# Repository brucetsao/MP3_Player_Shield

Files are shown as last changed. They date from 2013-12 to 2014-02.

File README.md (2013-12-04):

MP3 Player Shield 
NOTE: This branch is currently under Revision
==================

[MP3 Player Shield  
*MP3 Player Shield (SEN-11084)*](https://www.sparkfun.com/products/10628)

The MP3 Player Shield has a microSD socket, VS1053 decoder IC and all the supporting circuitry to be able to decode and play MP3s from an Arduino.

Repository Contents
-------------------
* **/firmware** - Multiple examples of how to read MP3 files and send them to the VS1053.
* **/hardware** - All Eagle design files (.brd, .sch)

License Information
-------------------

The hardware is released under [Creative Commons Share-alike 3.0](http://creativecommons.org/licenses/by-sa/3.0/).  

All other code is open source so please feel free to do anything you want with it; you buy me a beer if you use this and we meet someday ([Beerware license](http://en.wikipedia.org/wiki/Beerware)).

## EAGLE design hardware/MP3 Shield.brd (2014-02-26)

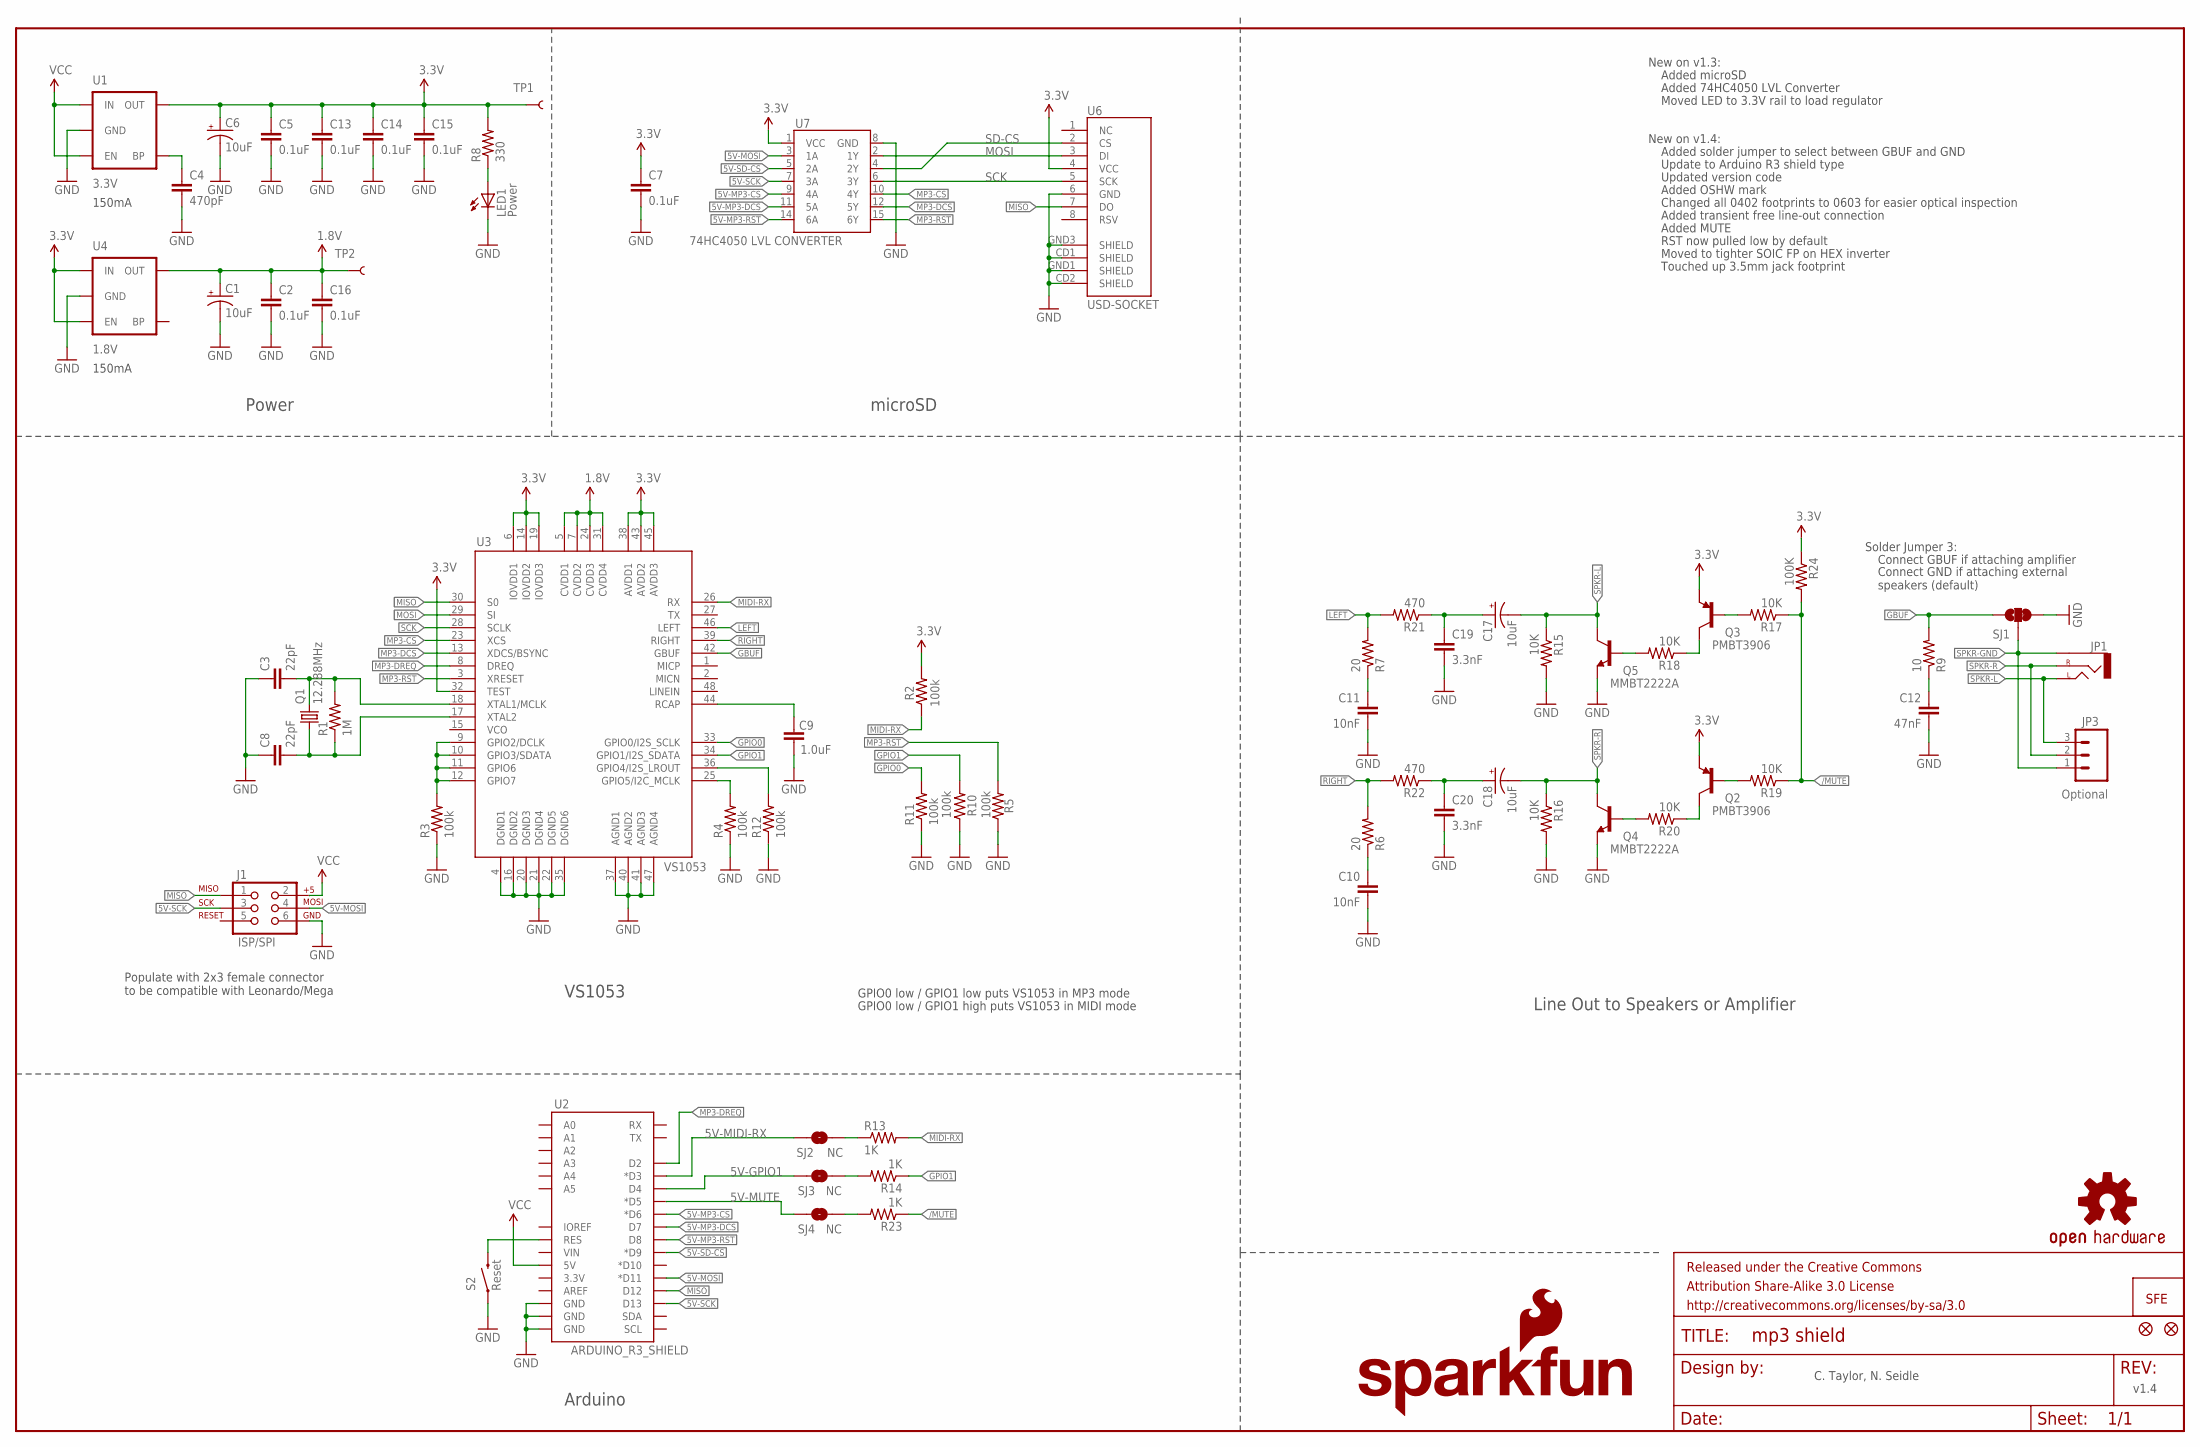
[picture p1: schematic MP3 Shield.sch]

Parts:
C1, C6, C17, C18: 10uF; EIA3216
C2, C5, C7, C13, C14, C15, C16: 0.1uF; 0603-CAP
C3, C8: 22pF; 0603-CAP
C4: 470pF; 0603-CAP
C9: 1.0uF; 0603-CAP
C10, C11: 10nF; 0603-CAP
C12: 47nF; 0603-CAP
C19, C20: 3.3nF; 0603-CAP
FRAME1: FRAME-LEDGER; CREATIVE_COMMONS
J1: ISP/SPI; 2X3
JP1: AUDIO-JACKSMD2; AUDIO-JACK-3.5MM-SMD
JP3: Optional; 1X03
LED1: Power; LED-0603
LOGO1: OSHW-LOGOS; OSHW-LOGO-S
LOGO2: SFE_LOGO_NAME_FLAME.1_INCH; SFE_LOGO_NAME_FLAME_.1
Q1: 12.288MHz; CRYSTAL-SMD-5X3
Q2, Q3: PMBT3906; SOT23-3
Q4, Q5: MMBT2222A; SOT23-3
R1: 1M; 0603-RES
R2, R3, R4, R5, R10, R11, R12: 100k; 0603-RES
R6, R7: 20; 0603-RES
R8: 330; 0603-RES
R9: 10; 0603-RES
R13, R14, R23: 1K; 0603-RES
R15, R16, R17, R18, R19, R20: 10K; 0603-RES
R21, R22: 470; 0603-RES
R24: 100K; 0603-RES
S2: Reset; TACTILE_SWITCH_SMD
SJ1: SOLDERJUMPER_2WAYPASTE2&3; SJ_3_PASTE2&3
SJ2, SJ3, SJ4: NC; SJ_2S-TRACE
TP1, TP2: TEST-POINT3X5; PAD.03X.05
U1: 3.3V; SOT23-5
U2: ARDUINO_R3_SHIELD; UNO_R3_SHIELD
U3: VS1053; LQFP-48
U4: 1.8V; SC70
U6: USD-SOCKET; MICRO-SD-SOCKET-PP
U7: 74HC4050 LVL CONVERTER; SO016
U$4, U$5: FIDUCIAL1X2; FIDUCIAL-1X2
U$8: LOGO-SFENEW; SFE-NEW-WEBLOGO

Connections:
1.8V: C1.A (+), C2.1, C16.1, TP2.P$1, U3.5 (CVDD1), U3.7 (CVDD2), U3.24 (CVDD3), U3.31 (CVDD4), U4.5 (OUT)
3.3V: C5.1, C6.A (+), C7.1, C13.1, C14.1, C15.1, Q2.2 (E), Q3.2 (E), R2.2, R8.2, R24.1, TP1.P$1, U1.5 (OUT), U3.6 (IOVDD1), U3.14 (IOVDD2), U3.19 (IOVDD3), U3.32 (TEST), U3.38 (AVDD1), U3.43 (AVDD2), U3.45 (AVDD3), U4.1 (IN), U4.3 (EN), U6.4 (VCC), U7.1 (VCC)
5V-GPIO1: SJ3.2, U2.D4
5V-MIDI-RX: SJ2.1, U2.D3 (*D3)
5V-MOSI: J1.4, U2.D11 (*D11), U7.3 (1A)
5V-MP3-CS: U2.D6 (*D6), U7.9 (4A)
5V-MP3-DCS: U2.D7, U7.11 (5A)
5V-MP3-RST: U2.D8, U7.14 (6A)
5V-MUTE: SJ4.2, U2.D5 (*D5)
5V-SCK: J1.3, U2.D13, U7.7 (3A)
5V-SD-CS: U2.D9 (*D9), U7.5 (2A)
/MUTE: R17.1, R19.1, R23.1, R24.2
ARST: S2.3 (2), U2.RES
G1: R3.2, U3.9 (GPIO2/DCLK), U3.10 (GPIO3/SDATA), U3.11 (GPIO6), U3.12 (GPIO7)
G2: R4.2, U3.25 (GPIO5/I2C_MCLK)
GBUF: R9.2, SJ1.1, U3.42 (GBUF)
GND: C1.C (-), C2.2, C3.1, C4.2, C5.2, C6.C (-), C7.2, C8.1, C9.1, C10.2, C11.2, C12.2, C13.2, C14.2, C15.2, C16.2, C19.2, C20.2, J1.6, LED1.C, Q4.2 (E), Q5.2 (E), R3.1, R4.1, R5.1, R10.1, R11.1, R12.1, R15.2, R16.2, S2.1, SJ1.3, U1.2 (GND), U2.GND@0 (GND), U2.GND@1 (GND), U2.GND@2 (GND), U3.4 (DGND1), U3.16 (DGND2), U3.20 (DGND3), U3.21 (DGND4), U3.22 (DGND5), U3.35 (DGND6), U3.37 (AGND1), U3.40 (AGND2), U3.41 (AGND3), U3.47 (AGND4), U4.2 (GND), U6.6 (GND), U6.CD1 (SHIELD), U6.CD2 (SHIELD), U6.GND1 (SHIELD), U6.GND3 (SHIELD), U7.8 (GND)
GPIO0: R11.2, U3.33 (GPIO0/I2S_SCLK)
GPIO1: R10.2, R14.1, U3.34 (GPIO1/I2S_SDATA)
GPIO4: R12.2, U3.36 (GPIO4/I2S_LROUT)
LEFT: R7.2, R21.2, U3.46 (LEFT)
MIDI-RX: R2.1, R13.2, U3.26 (RX)
MISO: J1.1, U2.D12, U3.30 (S0), U6.7 (DO)
MOSI: U3.29 (SI), U6.3 (DI), U7.2 (1Y)
MP3-CS: U3.23 (XCS), U7.10 (4Y)
MP3-DCS: U3.13 (XDCS/BSYNC), U7.12 (5Y)
MP3-DREQ: U2.D2, U3.8 (DREQ)
MP3-RST: R5.2, U3.3 (XRESET), U7.15 (6Y)
unnamed: Q4.1 (B), R20.2
unnamed: C12.1, R9.1
unnamed: C10.1, R6.1
unnamed: R14.2, SJ3.1
unnamed: C11.1, R7.1
unnamed: LED1.A, R8.1
unnamed: Q2.3 (C), R20.1
unnamed: R13.1, SJ2.2
unnamed: C3.2, Q1.3 (2), R1.2, U3.18 (XTAL1/MCLK)
unnamed: C8.2, Q1.1, R1.1, U3.17 (XTAL2)
unnamed: Q2.1 (B), R19.2
unnamed: Q5.1 (B), R18.2
unnamed: R23.2, SJ4.1
unnamed: Q3.3 (C), R18.1
unnamed: Q3.1 (B), R17.2
unnamed: C18.A (+), C20.1, R22.1
unnamed: C17.A (+), C19.1, R21.1
unnamed: C4.1, U1.4 (BP)
RCAP: C9.2, U3.44 (RCAP)
RIGHT: R6.2, R22.2, U3.39 (RIGHT)
SCK: U3.28 (SCLK), U6.5 (SCK), U7.6 (3Y)
SD-CS: U6.2 (CS), U7.4 (2Y)
SPKR-GND: JP1.SLEEVE, JP3.1, SJ1.2
SPKR-L: C17.C (-), JP1.TIP (LEFT), JP3.3, Q5.3 (C), R15.1
SPKR-R: C18.C (-), JP1.RING (RIGHT), JP3.2, Q4.3 (C), R16.1
VCC: J1.2, U1.1 (IN), U1.3 (EN), U2.5V

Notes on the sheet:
GPIO0 low / GPIO1 high puts VS1053 in MIDI mode
C. Taylor, N. Seidle
New on v1.3:
GPIO0 low / GPIO1 low puts VS1053 in MP3 mode
microSD
Power
Line Out to Speakers or Amplifier
Arduino
VS1053
Moved LED to 3.3V rail to load regulator
Added microSD
Added 74HC4050 LVL Converter
New on v1.4:
Added solder jumper to select between GBUF and GND
Connect GBUF if attaching amplifier
Connect GND if attaching external speakers (default)
Update to Arduino R3 shield type
Updated version code
Added OSHW mark
Changed all 0402 footprints to 0603 for easier optical inspection
Added transient free line-out connection
Added MUTE
Solder Jumper 3:
150mA
v1.4
RST now pulled low by default
Populate with 2x3 female connector to be compatible with Leonardo/Mega
Moved to tighter SOIC FP on HEX inverter
Touched up 3.5mm jack footprint

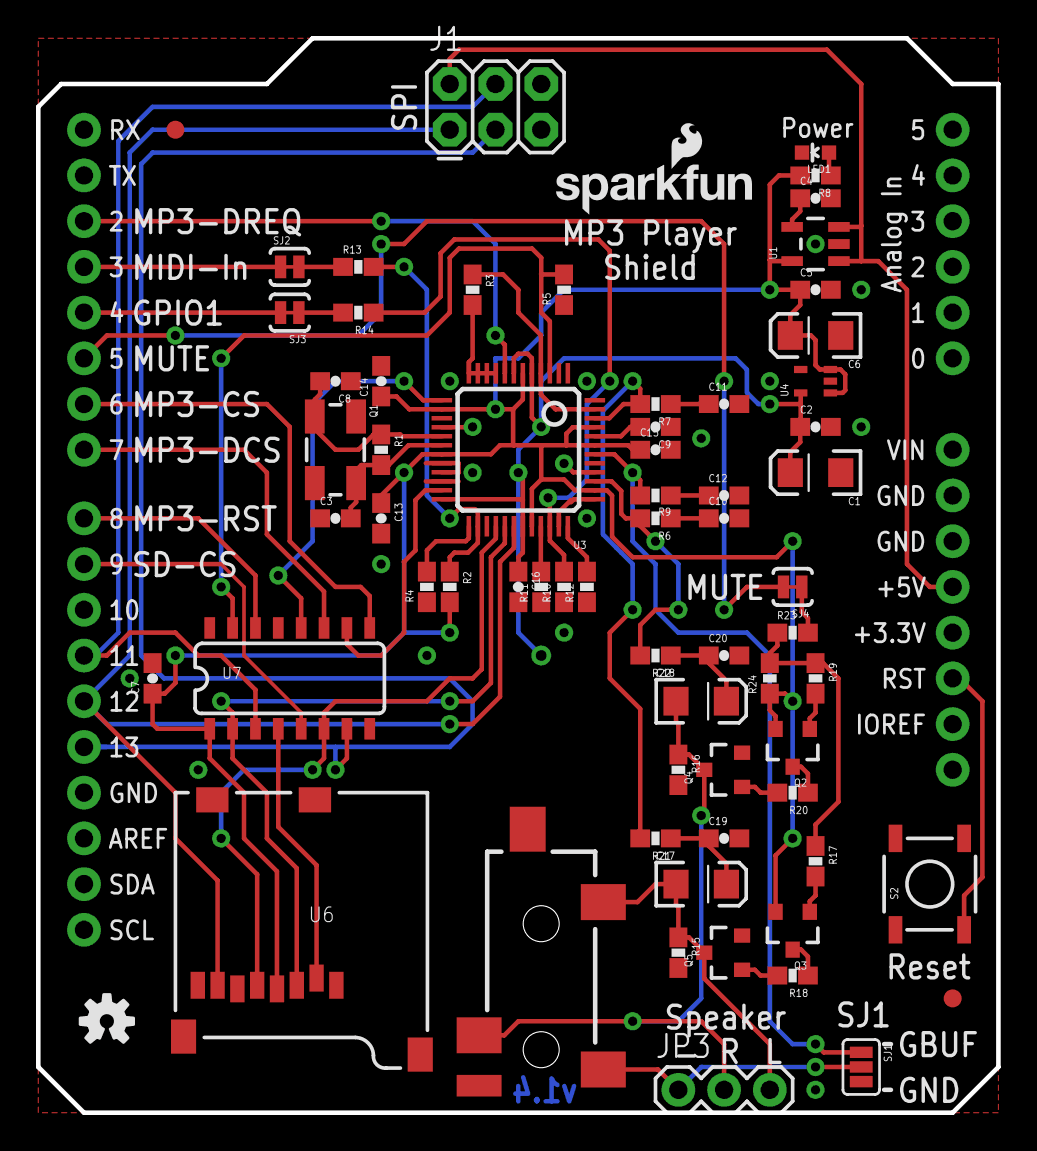
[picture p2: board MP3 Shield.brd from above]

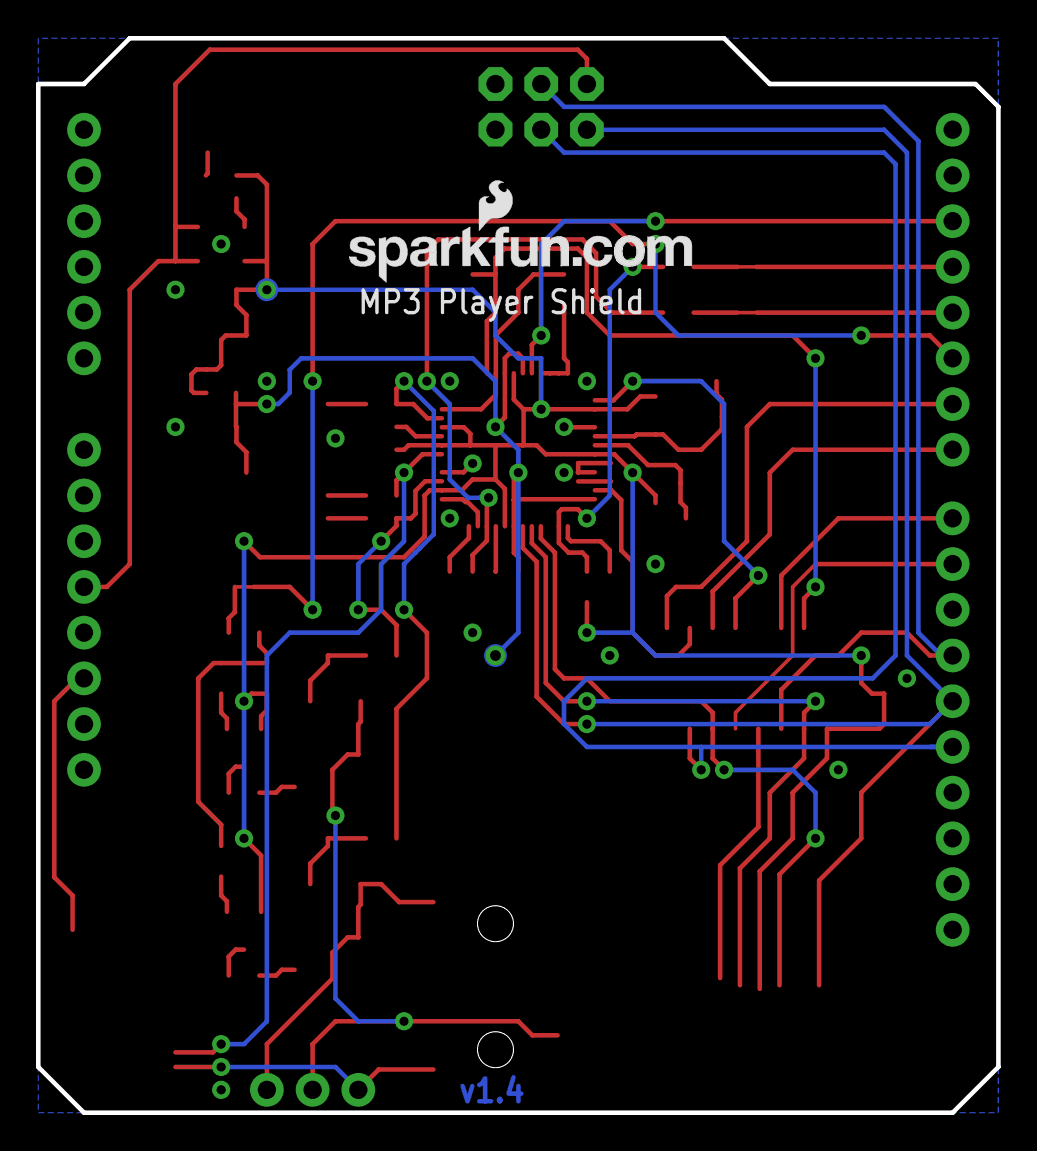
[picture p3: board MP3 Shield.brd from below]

Board: 2 copper layers, 53.3 x 59.7 mm, 72 parts (3 on the bottom side), 54 nets.

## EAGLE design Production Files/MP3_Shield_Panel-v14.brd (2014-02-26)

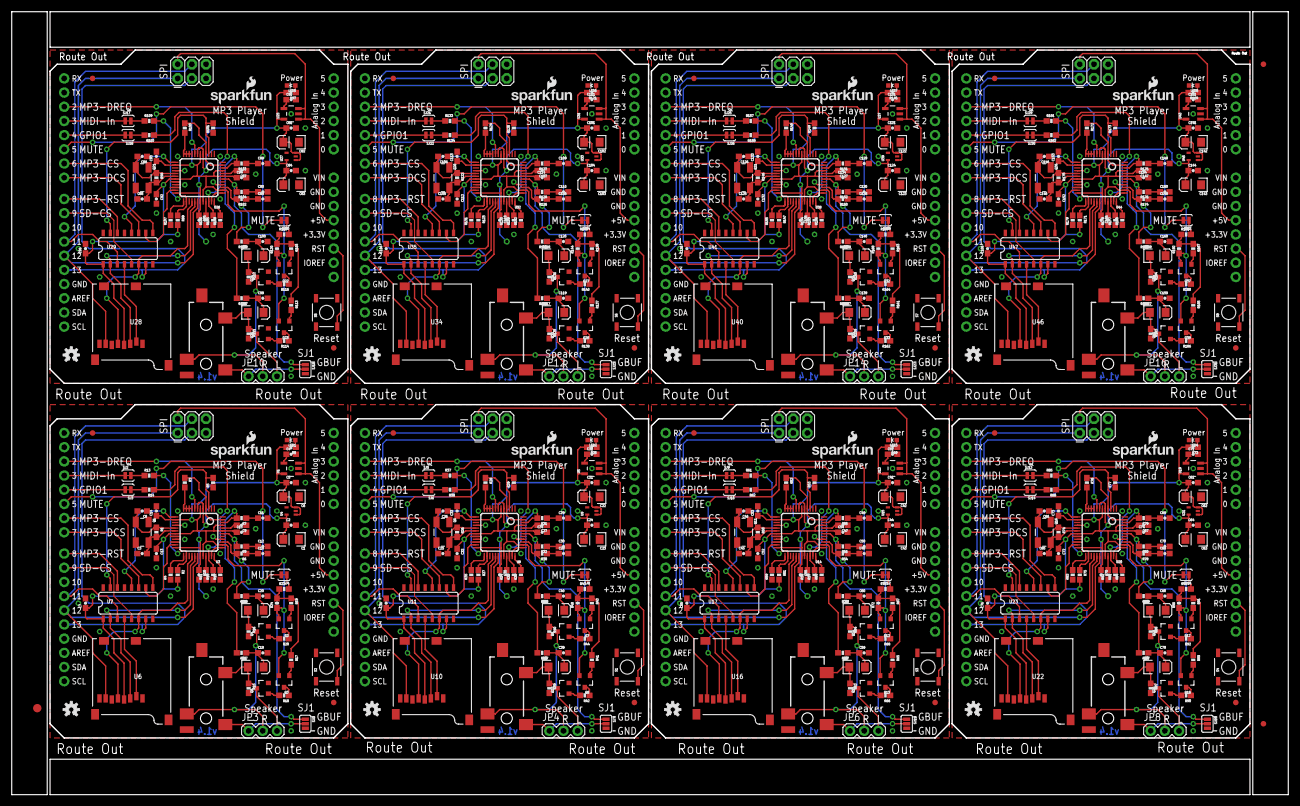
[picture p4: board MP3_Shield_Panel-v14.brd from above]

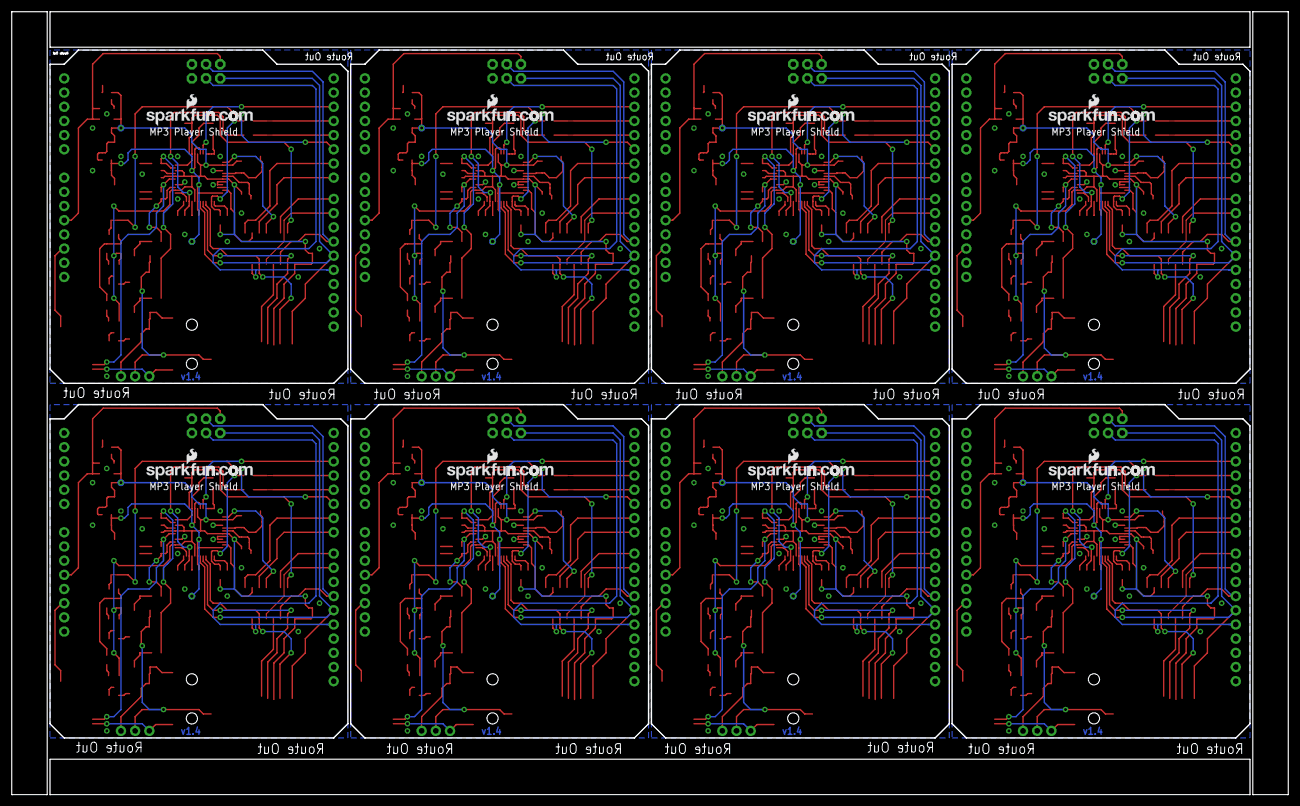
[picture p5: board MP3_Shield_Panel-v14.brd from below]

Board: 2 copper layers, 228.6 x 140.2 mm, 571 parts (24 on the bottom side), 432 nets.

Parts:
C1, C6, C17, C18, C22, C23, C37, C38, C42, C43, C57, C58, C62, C63, C77, C78, C82, C83, C97, C98, C102, C103, C117, C118, C122, C123, C137, C138, C142, C143, C157, C158: 10uF; EIA3216
C2, C5, C7, C13, C14, C15, C16, C21, C24, C32, C33, C34, C35, C36, C41, C44, C52, C53, C54, C55, C56, C61, C64, C72, C73, C74, C75, C76, C81, C84, C92, C93, C94, C95, C96, C101, C104, C112, C113, C114, C115, C116, C121, C124, C132, C133, C134, C135, C136, C141, C144, C152, C153, C154, C155, C156: 0.1uF; 0603-CAP
C3, C8, C25, C26, C45, C46, C65, C66, C85, C86, C105, C106, C125, C126, C145, C146: 22pF; 0603-CAP
C4, C31, C51, C71, C91, C111, C131, C151: 470pF; 0603-CAP
C9, C27, C47, C67, C87, C107, C127, C147: 1.0uF; 0603-CAP
C10, C11, C28, C29, C48, C49, C68, C69, C88, C89, C108, C109, C128, C129, C148, C149: 10nF; 0603-CAP
C12, C30, C50, C70, C90, C110, C130, C150: 47nF; 0603-CAP
C19, C20, C39, C40, C59, C60, C79, C80, C99, C100, C119, C120, C139, C140, C159, C160: 3.3nF; 0603-CAP
E$1: FIDUCIAL-1.5X3
E$4, E$5: FIDUCIAL-1X2
J1, J2, J3, J4, J5, J6, J7, J8: ISP/SPI; 2X3
JP1, JP2, JP5, JP7, JP9, JP11, JP13, JP15: AUDIO-JACK-3.5MM-SMD
JP3, JP4, JP6, JP8, JP10, JP12, JP14, JP16: Optional; 1X03
LED1, LED2, LED3, LED4, LED5, LED6, LED7, LED8: Power; LED-0603
LOGO1, LOGO3, LOGO5, LOGO7, LOGO9, LOGO11, LOGO13, LOGO15: OSHW-LOGOS; OSHW-LOGO-S
LOGO2, LOGO4, LOGO6, LOGO8, LOGO10, LOGO12, LOGO14, LOGO16: SFE_LOGO_NAME_FLAME.1_INCH; SFE_LOGO_NAME_FLAME_.1
Q1, Q6, Q11, Q16, Q21, Q26, Q31, Q36: 12.288MHz; CRYSTAL-SMD-5X3
Q2, Q3, Q7, Q8, Q12, Q13, Q17, Q18, Q22, Q23, Q27, Q28, Q32, Q33, Q37, Q38: PMBT3906; SOT23-3
Q4, Q5, Q9, Q10, Q14, Q15, Q19, Q20, Q24, Q25, Q29, Q30, Q34, Q35, Q39, Q40: MMBT2222A; SOT23-3
R1, R26, R50, R74, R98, R122, R146, R170: 1M; 0603-RES
R2, R3, R4, R5, R10, R11, R12, R27, R28, R29, R33, R34, R35, R36, R51, R52, R53, R57, R58, R59, R60, R75, R76, R77, R81, R82, R83, R84, R99, R100, R101, R105, R106, R107, R108, R123, R124, R125, R129, R130, R131, R132, R147, R148, R149, R153, R154, R155, R156, R171, R172, R173, R177, R178, R179, R180: 100k; 0603-RES
R6, R7, R30, R31, R54, R55, R78, R79, R102, R103, R126, R127, R150, R151, R174, R175: 20; 0603-RES
R8, R25, R49, R73, R97, R121, R145, R169: 330; 0603-RES
R9, R32, R56, R80, R104, R128, R152, R176: 10; 0603-RES
R13, R14, R23, R37, R38, R47, R61, R62, R71, R85, R86, R95, R109, R110, R119, R133, R134, R143, R157, R158, R167, R181, R182, R191: 1K; 0603-RES
R15, R16, R17, R18, R19, R20, R39, R40, R41, R42, R43, R44, R63, R64, R65, R66, R67, R68, R87, R88, R89, R90, R91, R92, R111, R112, R113, R114, R115, R116, R135, R136, R137, R138, R139, R140, R159, R160, R161, R162, R163, R164, R183, R184, R185, R186, R187, R188: 10K; 0603-RES
R21, R22, R45, R46, R69, R70, R93, R94, R117, R118, R141, R142, R165, R166, R189, R190: 470; 0603-RES
R24, R48, R72, R96, R120, R144, R168, R192: 100K; 0603-RES
S1, S2, S3, S4, S5, S6, S7, S8: Reset; TACTILE_SWITCH_SMD
SJ1, SJ7, SJ11, SJ15, SJ19, SJ23, SJ27, SJ31: SJ_3_PASTE2&3
SJ2, SJ3, SJ4, SJ5, SJ6, SJ8, SJ9, SJ10, SJ12, SJ13, SJ14, SJ16, SJ17, SJ18, SJ20, SJ21, SJ22, SJ24, SJ25, SJ26, SJ28, SJ29, SJ30, SJ32: NC; SJ_2S-TRACE
TP1, TP2, TP3, TP4, TP5, TP6, TP7, TP8, TP9, TP10, TP11, TP12, TP13, TP14, TP15, TP16: PAD.03X.05
U1, U5, U13, U19, U25, U31, U37, U43: 3.3V; SOT23-5
U2, U12, U18, U24, U30, U36, U42, U48: ARDUINO_R3_SHIELD; UNO_R3_SHIELD
U3, U8, U14, U20, U26, U32, U38, U44: VS1053; LQFP-48
U4, U9, U15, U21, U27, U33, U39, U45: 1.8V; SC70
U6, U10, U16, U22, U28, U34, U40, U46: USD-SOCKET; MICRO-SD-SOCKET-PP
U7, U11, U17, U23, U29, U35, U41, U47: 74HC4050 LVL CONVERTER; SO016
U$1, U$2, U$4, U$5, U$6, U$7, U$10, U$11, U$13, U$14, U$16, U$17, U$19, U$20, U$22, U$23: FIDUCIAL1X2; FIDUCIAL-1X2
U$3, U$8, U$9, U$12, U$15, U$18, U$21, U$24: LOGO-SFENEW; SFE-NEW-WEBLOGO

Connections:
1.8V: C1.A, C2.1, C16.1, TP2.P$1, U3.5, U3.7, U3.24, U3.31, U4.5
1.8V1: C23.A, C24.1, C35.1, TP4.P$1, U8.5, U8.7, U8.24, U8.31, U9.5
1.8V2: C43.A, C44.1, C55.1, TP6.P$1, U14.5, U14.7, U14.24, U14.31, U15.5
1.8V3: C63.A, C64.1, C75.1, TP8.P$1, U20.5, U20.7, U20.24, U20.31, U21.5
1.8V4: C83.A, C84.1, C95.1, TP10.P$1, U26.5, U26.7, U26.24, U26.31, U27.5
1.8V5: C103.A, C104.1, C115.1, TP12.P$1, U32.5, U32.7, U32.24, U32.31, U33.5
1.8V6: C123.A, C124.1, C135.1, TP14.P$1, U38.5, U38.7, U38.24, U38.31, U39.5
1.8V7: C143.A, C144.1, C155.1, TP16.P$1, U44.5, U44.7, U44.24, U44.31, U45.5
3.3V: C5.1, C6.A, C7.1, C13.1, C14.1, C15.1, Q2.2, Q3.2, R2.2, R8.2, R24.1, TP1.P$1, U1.5, U3.6, U3.14, U3.19, U3.32, U3.38, U3.43, U3.45, U4.1, U4.3, U6.4, U7.1
3.3V1: C21.1, C22.A, C32.1, C33.1, C34.1, C36.1, Q7.2, Q8.2, R25.2, R27.2, R48.1, TP3.P$1, U5.5, U8.6, U8.14, U8.19, U8.32, U8.38, U8.43, U8.45, U9.1, U9.3, U10.4, U11.1
3.3V2: C41.1, C42.A, C52.1, C53.1, C54.1, C56.1, Q12.2, Q13.2, R49.2, R51.2, R72.1, TP5.P$1, U13.5, U14.6, U14.14, U14.19, U14.32, U14.38, U14.43, U14.45, U15.1, U15.3, U16.4, U17.1
3.3V3: C61.1, C62.A, C72.1, C73.1, C74.1, C76.1, Q17.2, Q18.2, R73.2, R75.2, R96.1, TP7.P$1, U19.5, U20.6, U20.14, U20.19, U20.32, U20.38, U20.43, U20.45, U21.1, U21.3, U22.4, U23.1
3.3V4: C81.1, C82.A, C92.1, C93.1, C94.1, C96.1, Q22.2, Q23.2, R97.2, R99.2, R120.1, TP9.P$1, U25.5, U26.6, U26.14, U26.19, U26.32, U26.38, U26.43, U26.45, U27.1, U27.3, U28.4, U29.1
3.3V5: C101.1, C102.A, C112.1, C113.1, C114.1, C116.1, Q27.2, Q28.2, R121.2, R123.2, R144.1, TP11.P$1, U31.5, U32.6, U32.14, U32.19, U32.32, U32.38, U32.43, U32.45, U33.1, U33.3, U34.4, U35.1
3.3V6: C121.1, C122.A, C132.1, C133.1, C134.1, C136.1, Q32.2, Q33.2, R145.2, R147.2, R168.1, TP13.P$1, U37.5, U38.6, U38.14, U38.19, U38.32, U38.38, U38.43, U38.45, U39.1, U39.3, U40.4, U41.1
3.3V7: C141.1, C142.A, C152.1, C153.1, C154.1, C156.1, Q37.2, Q38.2, R169.2, R171.2, R192.1, TP15.P$1, U43.5, U44.6, U44.14, U44.19, U44.32, U44.38, U44.43, U44.45, U45.1, U45.3, U46.4, U47.1
5V-GPIO1: SJ3.2, U2.D4
5V-GPIO2: SJ6.2, U12.D4
5V-GPIO3: SJ10.2, U18.D4
5V-GPIO4: SJ14.2, U24.D4
5V-GPIO5: SJ18.2, U30.D4
5V-GPIO6: SJ22.2, U36.D4
5V-GPIO7: SJ26.2, U42.D4
5V-GPIO8: SJ30.2, U48.D4
5V-MIDI-RX: SJ2.1, U2.D3
5V-MIDI-RX1: SJ5.1, U12.D3
5V-MIDI-RX2: SJ9.1, U18.D3
5V-MIDI-RX3: SJ13.1, U24.D3
5V-MIDI-RX4: SJ17.1, U30.D3
5V-MIDI-RX5: SJ21.1, U36.D3
5V-MIDI-RX6: SJ25.1, U42.D3
5V-MIDI-RX7: SJ29.1, U48.D3
5V-MOSI: J1.4, U2.D11, U7.3
5V-MOSI1: J2.4, U11.3, U12.D11
5V-MOSI2: J3.4, U17.3, U18.D11
5V-MOSI3: J4.4, U23.3, U24.D11
5V-MOSI4: J5.4, U29.3, U30.D11
5V-MOSI5: J6.4, U35.3, U36.D11
5V-MOSI6: J7.4, U41.3, U42.D11
5V-MOSI7: J8.4, U47.3, U48.D11
5V-MP3-CS: U2.D6, U7.9
5V-MP3-CS1: U11.9, U12.D6
5V-MP3-CS2: U17.9, U18.D6
5V-MP3-CS3: U23.9, U24.D6
5V-MP3-CS4: U29.9, U30.D6
5V-MP3-CS5: U35.9, U36.D6
5V-MP3-CS6: U41.9, U42.D6
5V-MP3-CS7: U47.9, U48.D6
5V-MP3-DCS: U2.D7, U7.11
5V-MP3-DCS1: U11.11, U12.D7
5V-MP3-DCS2: U17.11, U18.D7
5V-MP3-DCS3: U23.11, U24.D7
5V-MP3-DCS4: U29.11, U30.D7
5V-MP3-DCS5: U35.11, U36.D7
5V-MP3-DCS6: U41.11, U42.D7
5V-MP3-DCS7: U47.11, U48.D7
5V-MP3-RST: U2.D8, U7.14
5V-MP3-RST1: U11.14, U12.D8
5V-MP3-RST2: U17.14, U18.D8
5V-MP3-RST3: U23.14, U24.D8
5V-MP3-RST4: U29.14, U30.D8
5V-MP3-RST5: U35.14, U36.D8
5V-MP3-RST6: U41.14, U42.D8
5V-MP3-RST7: U47.14, U48.D8
5V-MUTE: SJ4.2, U2.D5
5V-MUTE1: SJ8.2, U12.D5
5V-MUTE2: SJ12.2, U18.D5
5V-MUTE3: SJ16.2, U24.D5
5V-MUTE4: SJ20.2, U30.D5
5V-MUTE5: SJ24.2, U36.D5
5V-MUTE6: SJ28.2, U42.D5
5V-MUTE7: SJ32.2, U48.D5
5V-SCK: J1.3, U2.D13, U7.7
5V-SCK1: J2.3, U11.7, U12.D13
5V-SCK2: J3.3, U17.7, U18.D13
5V-SCK3: J4.3, U23.7, U24.D13
5V-SCK4: J5.3, U29.7, U30.D13
5V-SCK5: J6.3, U35.7, U36.D13
5V-SCK6: J7.3, U41.7, U42.D13
5V-SCK7: J8.3, U47.7, U48.D13
5V-SD-CS: U2.D9, U7.5
5V-SD-CS1: U11.5, U12.D9
5V-SD-CS2: U17.5, U18.D9
5V-SD-CS3: U23.5, U24.D9
5V-SD-CS4: U29.5, U30.D9
5V-SD-CS5: U35.5, U36.D9
5V-SD-CS6: U41.5, U42.D9
5V-SD-CS7: U47.5, U48.D9
/MUTE: R17.1, R19.1, R23.1, R24.2
/MUTE1: R41.1, R43.1, R47.1, R48.2
/MUTE2: R65.1, R67.1, R71.1, R72.2
/MUTE3: R89.1, R91.1, R95.1, R96.2
/MUTE4: R113.1, R115.1, R119.1, R120.2
/MUTE5: R137.1, R139.1, R143.1, R144.2
/MUTE6: R161.1, R163.1, R167.1, R168.2
/MUTE7: R185.1, R187.1, R191.1, R192.2
ARST: S2.3, U2.RES
ARST1: S1.3, U12.RES
ARST2: S3.3, U18.RES
ARST3: S4.3, U24.RES
ARST4: S5.3, U30.RES
ARST5: S6.3, U36.RES
ARST6: S7.3, U42.RES
ARST7: S8.3, U48.RES
G1: R3.2, U3.9, U3.10, U3.11, U3.12
G2: R4.2, U3.25
G3: R28.2, U8.9, U8.10, U8.11, U8.12
G4: R35.2, U8.25
G5: R52.2, U14.9, U14.10, U14.11, U14.12
G6: R59.2, U14.25
G7: R76.2, U20.9, U20.10, U20.11, U20.12
G8: R83.2, U20.25
G9: R100.2, U26.9, U26.10, U26.11, U26.12
G10: R107.2, U26.25
G11: R124.2, U32.9, U32.10, U32.11, U32.12
G12: R131.2, U32.25
G13: R148.2, U38.9, U38.10, U38.11, U38.12
G14: R155.2, U38.25
G15: R172.2, U44.9, U44.10, U44.11, U44.12
G16: R179.2, U44.25
GBUF: R9.2, SJ1.1, U3.42
GBUF1: R32.2, SJ7.1, U8.42
GBUF2: R56.2, SJ11.1, U14.42
GBUF3: R80.2, SJ15.1, U20.42
GBUF4: R104.2, SJ19.1, U26.42
GBUF5: R128.2, SJ23.1, U32.42
GBUF6: R152.2, SJ27.1, U38.42
GBUF7: R176.2, SJ31.1, U44.42
GND: C1.C, C2.2, C3.1, C4.2, C5.2, C6.C, C7.2, C8.1, C9.1, C10.2, C11.2, C12.2, C13.2, C14.2, C15.2, C16.2, C19.2, C20.2, J1.6, LED1.C, Q4.2, Q5.2, R3.1, R4.1, R5.1, R10.1, R11.1, R12.1, R15.2, R16.2, S2.1, SJ1.3, U1.2, U2.GND@0, U2.GND@1, U2.GND@2, U3.4, U3.16, U3.20, U3.21, U3.22, U3.35, U3.37, U3.40, U3.41, U3.47, U4.2, U6.6, U6.CD1, U6.CD2, U6.GND1, U6.GND3, U7.8
GND1: C21.2, C22.C, C23.C, C24.2, C25.1, C26.1, C27.1, C28.2, C29.2, C30.2, C31.2, C32.2, C33.2, C34.2, C35.2, C36.2, C39.2, C40.2, J2.6, LED2.C, Q9.2, Q10.2, R28.1, R29.1, R33.1, R34.1, R35.1, R36.1, R39.2, R40.2, S1.1, SJ7.3, U5.2, U8.4, U8.16, U8.20, U8.21, U8.22, U8.35, U8.37, U8.40, U8.41, U8.47, U9.2, U10.6, U10.CD1, U10.CD2, U10.GND1, U10.GND3, U11.8, U12.GND@0, U12.GND@1, U12.GND@2
GND2: C41.2, C42.C, C43.C, C44.2, C45.1, C46.1, C47.1, C48.2, C49.2, C50.2, C51.2, C52.2, C53.2, C54.2, C55.2, C56.2, C59.2, C60.2, J3.6, LED3.C, Q14.2, Q15.2, R52.1, R53.1, R57.1, R58.1, R59.1, R60.1, R63.2, R64.2, S3.1, SJ11.3, U13.2, U14.4, U14.16, U14.20, U14.21, U14.22, U14.35, U14.37, U14.40, U14.41, U14.47, U15.2, U16.6, U16.CD1, U16.CD2, U16.GND1, U16.GND3, U17.8, U18.GND@0, U18.GND@1, U18.GND@2
GND3: C61.2, C62.C, C63.C, C64.2, C65.1, C66.1, C67.1, C68.2, C69.2, C70.2, C71.2, C72.2, C73.2, C74.2, C75.2, C76.2, C79.2, C80.2, J4.6, LED4.C, Q19.2, Q20.2, R76.1, R77.1, R81.1, R82.1, R83.1, R84.1, R87.2, R88.2, S4.1, SJ15.3, U19.2, U20.4, U20.16, U20.20, U20.21, U20.22, U20.35, U20.37, U20.40, U20.41, U20.47, U21.2, U22.6, U22.CD1, U22.CD2, U22.GND1, U22.GND3, U23.8, U24.GND@0, U24.GND@1, U24.GND@2
GND4: C81.2, C82.C, C83.C, C84.2, C85.1, C86.1, C87.1, C88.2, C89.2, C90.2, C91.2, C92.2, C93.2, C94.2, C95.2, C96.2, C99.2, C100.2, J5.6, LED5.C, Q24.2, Q25.2, R100.1, R101.1, R105.1, R106.1, R107.1, R108.1, R111.2, R112.2, S5.1, SJ19.3, U25.2, U26.4, U26.16, U26.20, U26.21, U26.22, U26.35, U26.37, U26.40, U26.41, U26.47, U27.2, U28.6, U28.CD1, U28.CD2, U28.GND1, U28.GND3, U29.8, U30.GND@0, U30.GND@1, U30.GND@2
GND5: C101.2, C102.C, C103.C, C104.2, C105.1, C106.1, C107.1, C108.2, C109.2, C110.2, C111.2, C112.2, C113.2, C114.2, C115.2, C116.2, C119.2, C120.2, J6.6, LED6.C, Q29.2, Q30.2, R124.1, R125.1, R129.1, R130.1, R131.1, R132.1, R135.2, R136.2, S6.1, SJ23.3, U31.2, U32.4, U32.16, U32.20, U32.21, U32.22, U32.35, U32.37, U32.40, U32.41, U32.47, U33.2, U34.6, U34.CD1, U34.CD2, U34.GND1, U34.GND3, U35.8, U36.GND@0, U36.GND@1, U36.GND@2
GND6: C121.2, C122.C, C123.C, C124.2, C125.1, C126.1, C127.1, C128.2, C129.2, C130.2, C131.2, C132.2, C133.2, C134.2, C135.2, C136.2, C139.2, C140.2, J7.6, LED7.C, Q34.2, Q35.2, R148.1, R149.1, R153.1, R154.1, R155.1, R156.1, R159.2, R160.2, S7.1, SJ27.3, U37.2, U38.4, U38.16, U38.20, U38.21, U38.22, U38.35, U38.37, U38.40, U38.41, U38.47, U39.2, U40.6, U40.CD1, U40.CD2, U40.GND1, U40.GND3, U41.8, U42.GND@0, U42.GND@1, U42.GND@2
GND7: C141.2, C142.C, C143.C, C144.2, C145.1, C146.1, C147.1, C148.2, C149.2, C150.2, C151.2, C152.2, C153.2, C154.2, C155.2, C156.2, C159.2, C160.2, J8.6, LED8.C, Q39.2, Q40.2, R172.1, R173.1, R177.1, R178.1, R179.1, R180.1, R183.2, R184.2, S8.1, SJ31.3, U43.2, U44.4, U44.16, U44.20, U44.21, U44.22, U44.35, U44.37, U44.40, U44.41, U44.47, U45.2, U46.6, U46.CD1, U46.CD2, U46.GND1, U46.GND3, U47.8, U48.GND@0, U48.GND@1, U48.GND@2
GPIO0: R11.2, U3.33
GPIO1: R10.2, R14.1, U3.34
GPIO2: R34.2, U8.33
GPIO3: R33.2, R38.1, U8.34
GPIO4: R12.2, U3.36
GPIO5: R36.2, U8.36
GPIO6: R58.2, U14.33
GPIO7: R57.2, R62.1, U14.34
GPIO8: R60.2, U14.36
GPIO9: R82.2, U20.33
GPIO10: R81.2, R86.1, U20.34
GPIO11: R84.2, U20.36
GPIO12: R106.2, U26.33
GPIO13: R105.2, R110.1, U26.34
GPIO14: R108.2, U26.36
GPIO15: R130.2, U32.33
GPIO16: R129.2, R134.1, U32.34
GPIO17: R132.2, U32.36
GPIO18: R154.2, U38.33
GPIO19: R153.2, R158.1, U38.34
GPIO20: R156.2, U38.36
GPIO21: R178.2, U44.33
GPIO22: R177.2, R182.1, U44.34
GPIO23: R180.2, U44.36
LEFT: R7.2, R21.2, U3.46
LEFT1: R31.2, R45.2, U8.46
LEFT2: R55.2, R69.2, U14.46
LEFT3: R79.2, R93.2, U20.46
LEFT4: R103.2, R117.2, U26.46
LEFT5: R127.2, R141.2, U32.46
LEFT6: R151.2, R165.2, U38.46
LEFT7: R175.2, R189.2, U44.46
MIDI-RX: R2.1, R13.2, U3.26
MIDI-RX1: R27.1, R37.2, U8.26
MIDI-RX2: R51.1, R61.2, U14.26
MIDI-RX3: R75.1, R85.2, U20.26
MIDI-RX4: R99.1, R109.2, U26.26
MIDI-RX5: R123.1, R133.2, U32.26
MIDI-RX6: R147.1, R157.2, U38.26
MIDI-RX7: R171.1, R181.2, U44.26
MISO: J1.1, U2.D12, U3.30, U6.7
MISO1: J2.1, U8.30, U10.7, U12.D12
MISO2: J3.1, U14.30, U16.7, U18.D12
MISO3: J4.1, U20.30, U22.7, U24.D12
MISO4: J5.1, U26.30, U28.7, U30.D12
MISO5: J6.1, U32.30, U34.7, U36.D12
MISO6: J7.1, U38.30, U40.7, U42.D12
MISO7: J8.1, U44.30, U46.7, U48.D12
MOSI: U3.29, U6.3, U7.2
MOSI1: U8.29, U10.3, U11.2
MOSI2: U14.29, U16.3, U17.2
MOSI3: U20.29, U22.3, U23.2
MOSI4: U26.29, U28.3, U29.2
MOSI5: U32.29, U34.3, U35.2
MOSI6: U38.29, U40.3, U41.2
MOSI7: U44.29, U46.3, U47.2
MP3-CS: U3.23, U7.10
MP3-CS1: U8.23, U11.10
MP3-CS2: U14.23, U17.10
MP3-CS3: U20.23, U23.10
MP3-CS4: U26.23, U29.10
MP3-CS5: U32.23, U35.10
MP3-CS6: U38.23, U41.10
MP3-CS7: U44.23, U47.10
MP3-DCS: U3.13, U7.12
MP3-DCS1: U8.13, U11.12
MP3-DCS2: U14.13, U17.12
MP3-DCS3: U20.13, U23.12
MP3-DCS4: U26.13, U29.12
MP3-DCS5: U32.13, U35.12
MP3-DCS6: U38.13, U41.12
MP3-DCS7: U44.13, U47.12
MP3-DREQ: U2.D2, U3.8
MP3-DREQ1: U8.8, U12.D2
MP3-DREQ2: U14.8, U18.D2
MP3-DREQ3: U20.8, U24.D2
MP3-DREQ4: U26.8, U30.D2
MP3-DREQ5: U32.8, U36.D2
MP3-DREQ6: U38.8, U42.D2
MP3-DREQ7: U44.8, U48.D2
MP3-RST: R5.2, U3.3, U7.15
MP3-RST1: R29.2, U8.3, U11.15
MP3-RST2: R53.2, U14.3, U17.15
MP3-RST3: R77.2, U20.3, U23.15
MP3-RST4: R101.2, U26.3, U29.15
MP3-RST5: R125.2, U32.3, U35.15
MP3-RST6: R149.2, U38.3, U41.15
MP3-RST7: R173.2, U44.3, U47.15
unnamed: Q4.1, R20.2
unnamed: C12.1, R9.1
unnamed: C10.1, R6.1
unnamed: R14.2, SJ3.1
unnamed: C11.1, R7.1
unnamed: LED1.A, R8.1
unnamed: Q2.3, R20.1
unnamed: R13.1, SJ2.2
unnamed: C3.2, Q1.3, R1.2, U3.18
unnamed: C8.2, Q1.1, R1.1, U3.17
unnamed: Q2.1, R19.2
unnamed: Q5.1, R18.2
unnamed: LED2.A, R25.1
unnamed: R23.2, SJ4.1
unnamed: Q3.3, R18.1
unnamed: Q3.1, R17.2
unnamed: C18.A, C20.1, R22.1
unnamed: C25.2, Q6.3, R26.2, U8.18
unnamed: C17.A, C19.1, R21.1
unnamed: C26.2, Q6.1, R26.1, U8.17
unnamed: C30.1, R32.1
unnamed: C29.1, R31.1
unnamed: C28.1, R30.1
unnamed: C31.1, U5.4
unnamed: R37.1, SJ5.2
unnamed: R38.2, SJ6.1
unnamed: Q9.1, R44.2
unnamed: Q7.3, R44.1
unnamed: Q7.1, R43.2
unnamed: R47.2, SJ8.1
unnamed: Q10.1, R42.2
unnamed: Q8.3, R42.1
unnamed: Q8.1, R41.2
unnamed: C38.A, C40.1, R46.1
unnamed: C37.A, C39.1, R45.1
unnamed: LED3.A, R49.1
unnamed: C45.2, Q11.3, R50.2, U14.18
unnamed: C46.2, Q11.1, R50.1, U14.17
unnamed: C50.1, R56.1
unnamed: C49.1, R55.1
unnamed: C48.1, R54.1
unnamed: C51.1, U13.4
unnamed: R61.1, SJ9.2
unnamed: R62.2, SJ10.1
unnamed: Q14.1, R68.2
unnamed: Q12.3, R68.1
unnamed: Q12.1, R67.2
unnamed: R71.2, SJ12.1
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

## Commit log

2013-11-27 v1.4 Added line out protection, 0603 parts, OSHW mark.
    Many changes. 3.5mm jack now has output protection. Migrated to
    easier-to-optically-inspect 0603 sized parts. Changed to R3 type shield.
    Added solder jumper select between GBUF and GND. Added mute.
    [MP3 Shield-v13.brd, MP3 Shield-v13.sch, MP3 Shield.brd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]
2013-11-27 Final touches to layout
    [MP3 Shield.brd, MP3 Shield.sch]
2013-11-28 Adding transistor part #s
    Commits at 32,000 ft! Whooo!
    [MP3 Shield.brd, MP3 Shield.sch]
2013-12-02 Update README.md
    Adding note about how it is currently under revision.
2013-12-04 Added ISP connector for compatibility with Lenoardo/Mega.
    Routed SPI pins to ISP connector for more compatibility between Arduino
    versions.
    [MP3 Shield.brd, MP3 Shield.sch]
2013-12-04 Finished up and removed TODOs
    [MP3 Shield.sch]
2013-12-31 Updated 3.5mm jack and HEX inverter footprints.
    [MP3 Shield.brd, MP3 Shield.sch]
2014-02-26 created panel v14
    [MP3 Shield.brd, MP3_Shield_Panel-v14.brd]

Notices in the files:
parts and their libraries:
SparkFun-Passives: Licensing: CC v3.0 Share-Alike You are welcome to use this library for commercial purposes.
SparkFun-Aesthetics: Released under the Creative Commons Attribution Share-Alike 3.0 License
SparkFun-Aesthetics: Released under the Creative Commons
